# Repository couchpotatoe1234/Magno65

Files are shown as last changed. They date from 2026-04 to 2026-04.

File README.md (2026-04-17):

## Magno65
After weeks of hard work, here it is. The first prototype of the Magno65.
Screenshot 2026-04-17 at 3 54 28 PM
It will use N52 Neodymium magnets that are 5mmx2mm in the PCB and on the bottom of the case, allowing the plate and the PCB to levitate. 
Screenshot 2026-04-17 at 4 45 55 PM
The case itself is two parts, so it is 3D-printable. I currently have some untested firmware that will be tested when I make this project. Heres the aproximate BOM currently.
| Name | Purpose | Quantity | Total Cost (USD) | Link | Distributor |
|---|---|---|---|---|---|
| PCB | THE PCB, THE MAIN PART | 1 | 22.60 | https://jlcpcb.com | JLCPCB |
| N52 Neodymium magnets | to levitate the PCB (smallest pack I could find) | 1 | 12.04 | https://www.greenstuffworld.com/en/neodymium-magnets-n52/503-neodymium-magnets-5x2mm-50-units-n52.html | Green Stuff World |
| Keyboard Stabilizers | to stabilize the keycaps | 1 | 7.55 | https://www.temu.com/gold-plated-plate-mounted-stabilizer-for-custom-mechanical-keyboard-2u-6-25u-g-601100064817086.html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 | Temu |
| usb micro to usb-c cable | to connect the keyboard to the computer | 1 | 2.71 | https://www.temu.com/5a-type-c-to-micro-usb-fast-charging-cable-data-tansmission-stable-current-micro-usb-to-type-c-fast-charging-data-cable-for-samsung-xiaomi-huawe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 | Temu |
| Keycaps | to cap the keys | 1 | 6.93 | https://www.temu.com/chic-keycaps-with-contour-lines-featuring--cherry-profile-consisting-of-97-keys--double-shot--for---keycaps-have-see-through--and-lines-g-601100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 | Temu |
| Pi Pico | the brains of the operation | 1 | 3.11 | https://www.temu.com/1pc-sensor-module-pico-development-board--pico---supports--python-low-power-consumption--compatible-with--ide-and-csdk-industrial-electronics-no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 | Temu |
| Male pin headers | these are to connect the pi to the board | 1 | 2.27 | https://www.temu.com/dual-row-2-54mm-pitch-male-pin--40-pin-pcb-connector-strip-for--embedded-systems-g-606045468466813.html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 | Temu |
| 1N4148 | the diodes to make the keyboard work | 1 | 2.32 | https://www.temu.com/100pcs-1n4148-in4148-do-35-switch-diode-uncharged-other-material-for--g-601100062954719.html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 | Temu |
| Key switches | these are the whole point of a mechanical keyboard | 1 | 19.99 | https://www.wobkey.com/collections/all/products/keebmonkey-wobkey-rainy75-pre-lubed-hmx-jwk-switches | WOBKEY |

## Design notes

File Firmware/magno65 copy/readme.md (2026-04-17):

# magno65

magno65

*A short description of the keyboard/project*

* Keyboard Maintainer: [Couchpotatoe1234](https://github.com/Couchpotatoe1234)
* Hardware Supported: *The PCBs, controllers supported*
* Hardware Availability: *Links to where you can find this hardware*

Make example for this keyboard (after setting up your build environment):

    make magno65:default

Flashing example for this keyboard:

    make magno65:default:flash

See the [build environment setup](https://docs.qmk.fm/#/getting_started_build_tools) and the [make instructions](https://docs.qmk.fm/#/getting_started_make_guide) for more information. Brand new to QMK? Start with our [Complete Newbs Guide](https://docs.qmk.fm/#/newbs).

## Bootloader

Enter the bootloader in 3 ways:

* **Bootmagic reset**: Hold down the key at (0,0) in the matrix (usually the top left key or Escape) and plug in the keyboard
* **Physical reset button**: Briefly press the button on the back of the PCB - some may have pads you must short instead
* **Keycode in layout**: Press the key mapped to `QK_BOOT` if it is available

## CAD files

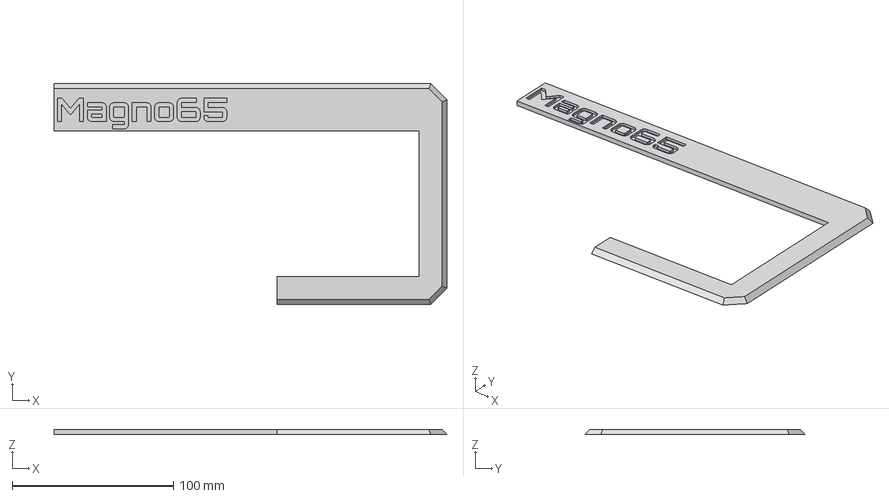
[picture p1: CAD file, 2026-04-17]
CAD/Magno65 parts - Top2.step
243.4 x 136.7 x 3.00 mm

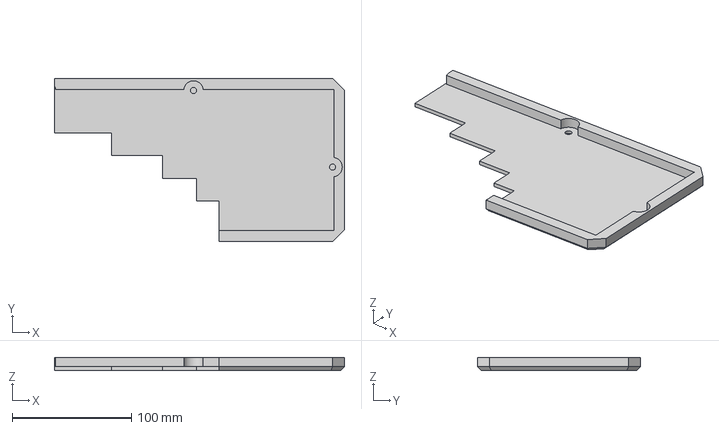
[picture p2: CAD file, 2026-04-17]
Production/Magno65 parts - Bottom1.step
243.4 x 136.7 x 10.5 mm

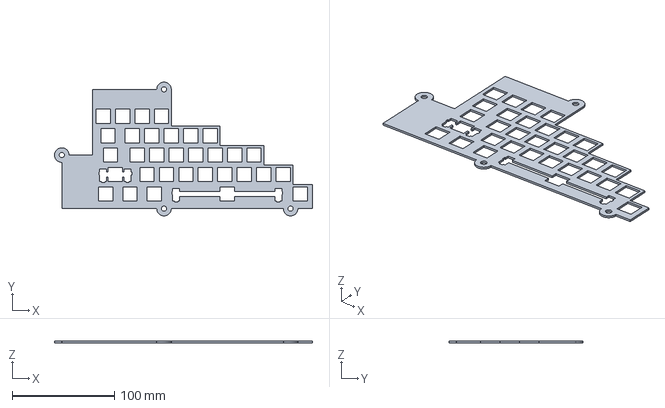
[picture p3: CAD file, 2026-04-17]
CAD/Magno65 parts - Plate1.step
252.4 x 130.9 x 1.60 mm

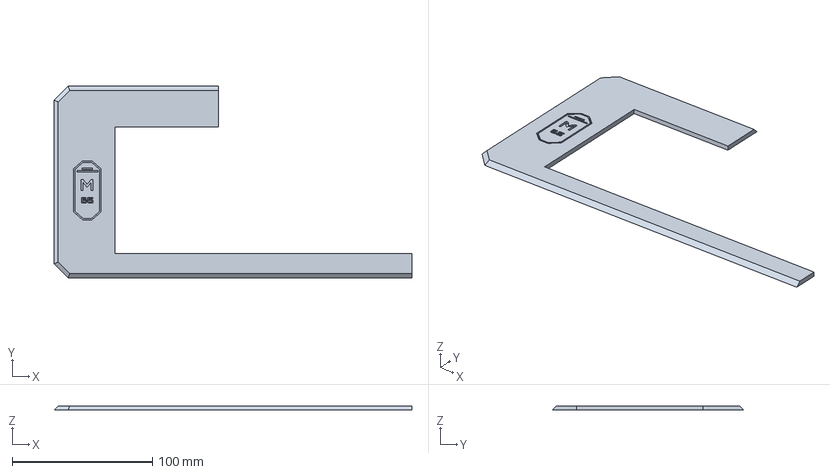
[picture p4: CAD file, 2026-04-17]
Production/Magno65 parts - Top1.step
255.3 x 136.7 x 3.00 mm

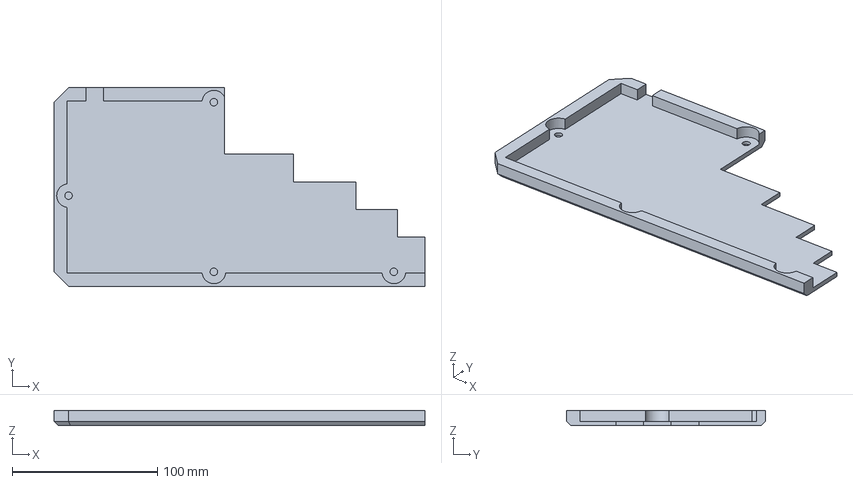
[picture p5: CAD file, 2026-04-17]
CAD/Magno65 parts - Bottom2.step
255.3 x 136.7 x 10.5 mm

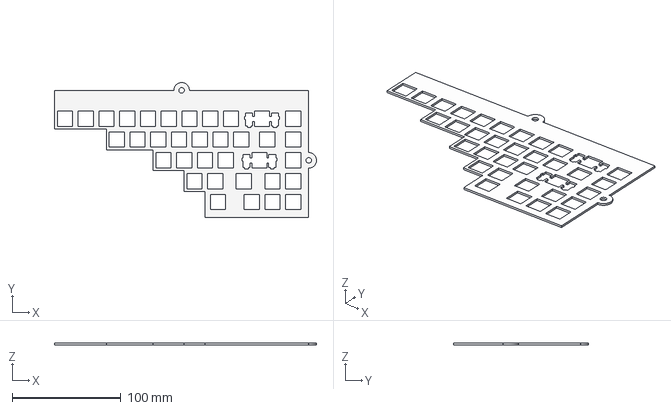
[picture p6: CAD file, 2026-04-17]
CAD/Magno65 parts - Plate2.step
240.5 x 123.8 x 1.60 mm

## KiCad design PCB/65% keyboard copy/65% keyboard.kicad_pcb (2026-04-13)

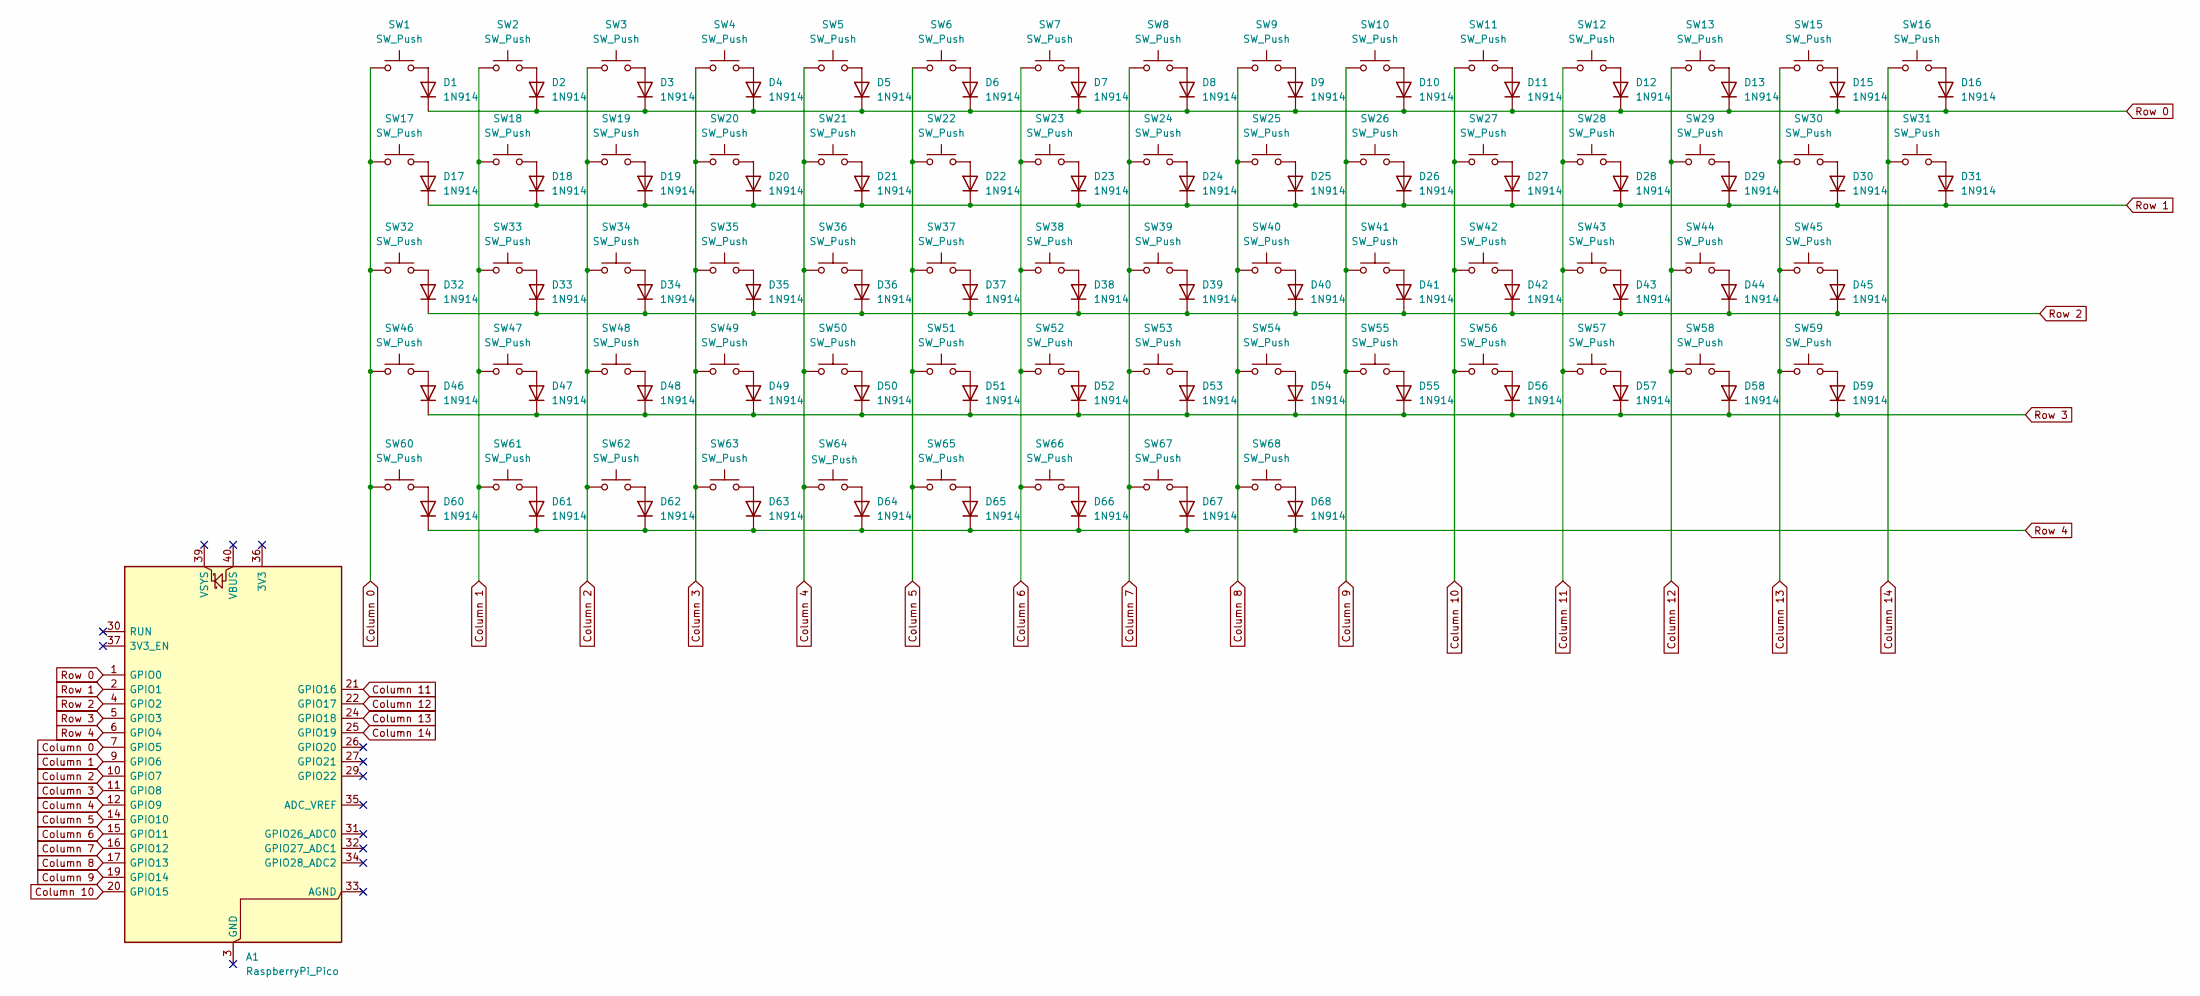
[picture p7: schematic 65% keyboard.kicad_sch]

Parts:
A1: RaspberryPi_Pico; RaspberryPi_Pico_Common_Unspecified
D1, D2, D3, D4, D5, D6, D7, D8, D9, D10, D11, D12, D13, D15, D16, D17, D18, D19, D20, D21, D22, D23, D24, D25, D26, D27, D28, D29, D30, D31, D32, D33, D34, D35, D36, D37, D38, D39, D40, D41, D42, D43, D44, D45, D46, D47, D48, D49, D50, D51, D52, D53, D54, D55, D56, D57, D58, D59, D60, D61, D62, D63, D64, D65, D66, D67, D68: 1N914; D_DO-35_SOD27_P7.62mm_Horizontal
SW1, SW2, SW3, SW4, SW5, SW6, SW7, SW8, SW9, SW10, SW11, SW12, SW13, SW16, SW17, SW18, SW19, SW20, SW21, SW22, SW23, SW24, SW25, SW26, SW27, SW28, SW29, SW30, SW31, SW32, SW33, SW34, SW35, SW36, SW37, SW38, SW39, SW40, SW41, SW42, SW43, SW45, SW47, SW48, SW49, SW50, SW51, SW52, SW53, SW54, SW55, SW56, SW57, SW58, SW59, SW60, SW61, SW64, SW65, SW66, SW67, SW68: SW_Push; SW_Cherry_MX_1.00u_PCB
SW15: SW_Push; SW_Cherry_MX_2.00u_Plate
SW44, SW46: SW_Push; SW_Cherry_MX_2.25u_Plate
SW62: SW_Push; SW_Cherry_MX_1.00u_Plate
SW63: SW_Push; SW_Cherry_MX_6.25u_Plate

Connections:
Column 0: A1.7 (GPIO5), SW1.1, SW17.1, SW32.1, SW46.1, SW60.1
Column 1: A1.9 (GPIO6), SW2.1, SW18.1, SW33.1, SW47.1, SW61.1
Column 2: A1.10 (GPIO7), SW3.1, SW19.1, SW34.1, SW48.1, SW62.1
Column 3: A1.11 (GPIO8), SW4.1, SW20.1, SW35.1, SW49.1, SW63.1
Column 4: A1.12 (GPIO9), SW5.1, SW21.1, SW36.1, SW50.1, SW64.1
Column 5: A1.14 (GPIO10), SW6.1, SW22.1, SW37.1, SW51.1, SW65.1
Column 6: A1.15 (GPIO11), SW7.1, SW23.1, SW38.1, SW52.1, SW66.1
Column 7: A1.16 (GPIO12), SW8.1, SW24.1, SW39.1, SW53.1, SW67.1
Column 8: A1.17 (GPIO13), SW9.1, SW25.1, SW40.1, SW54.1, SW68.1
Column 9: A1.19 (GPIO14), SW10.1, SW26.1, SW41.1, SW55.1
Column 10: A1.20 (GPIO15), SW11.1, SW27.1, SW42.1, SW56.1
Column 11: A1.21 (GPIO16), SW12.1, SW28.1, SW43.1, SW57.1
Column 12: A1.22 (GPIO17), SW13.1, SW29.1, SW44.1, SW58.1
Column 13: A1.24 (GPIO18), SW15.1, SW30.1, SW45.1, SW59.1
Column 14: A1.25 (GPIO19), SW16.1, SW31.1
unnamed: D1.2 (A), SW1.2
unnamed: D2.2 (A), SW2.2
unnamed: D3.2 (A), SW3.2
unnamed: D4.2 (A), SW4.2
unnamed: D5.2 (A), SW5.2
unnamed: D6.2 (A), SW6.2
unnamed: D7.2 (A), SW7.2
unnamed: D8.2 (A), SW8.2
unnamed: D9.2 (A), SW9.2
unnamed: D10.2 (A), SW10.2
unnamed: D11.2 (A), SW11.2
unnamed: D12.2 (A), SW12.2
unnamed: D13.2 (A), SW13.2
unnamed: D15.2 (A), SW15.2
unnamed: D16.2 (A), SW16.2
unnamed: D17.2 (A), SW17.2
unnamed: D18.2 (A), SW18.2
unnamed: D19.2 (A), SW19.2
unnamed: D20.2 (A), SW20.2
unnamed: D21.2 (A), SW21.2
unnamed: D22.2 (A), SW22.2
unnamed: D23.2 (A), SW23.2
unnamed: D24.2 (A), SW24.2
unnamed: D25.2 (A), SW25.2
unnamed: D26.2 (A), SW26.2
unnamed: D27.2 (A), SW27.2
unnamed: D28.2 (A), SW28.2
unnamed: D29.2 (A), SW29.2
unnamed: D30.2 (A), SW30.2
unnamed: D31.2 (A), SW31.2
unnamed: D32.2 (A), SW32.2
unnamed: D33.2 (A), SW33.2
unnamed: D34.2 (A), SW34.2
unnamed: D35.2 (A), SW35.2
unnamed: D36.2 (A), SW36.2
unnamed: D37.2 (A), SW37.2
unnamed: D38.2 (A), SW38.2
unnamed: D39.2 (A), SW39.2
unnamed: D40.2 (A), SW40.2
unnamed: D41.2 (A), SW41.2
unnamed: D42.2 (A), SW42.2
unnamed: D43.2 (A), SW43.2
unnamed: D44.2 (A), SW44.2
unnamed: D45.2 (A), SW45.2
unnamed: D46.2 (A), SW46.2
unnamed: D47.2 (A), SW47.2
unnamed: D48.2 (A), SW48.2
unnamed: D49.2 (A), SW49.2
unnamed: D50.2 (A), SW50.2
unnamed: D51.2 (A), SW51.2
unnamed: D52.2 (A), SW52.2
unnamed: D53.2 (A), SW53.2
unnamed: D54.2 (A), SW54.2
unnamed: D55.2 (A), SW55.2
unnamed: D56.2 (A), SW56.2
unnamed: D57.2 (A), SW57.2
unnamed: D58.2 (A), SW58.2
unnamed: D59.2 (A), SW59.2
unnamed: D60.2 (A), SW60.2
unnamed: D61.2 (A), SW61.2
unnamed: D62.2 (A), SW62.2
unnamed: D63.2 (A), SW63.2
unnamed: D64.2 (A), SW64.2
unnamed: D65.2 (A), SW65.2
unnamed: D66.2 (A), SW66.2
unnamed: D67.2 (A), SW67.2
unnamed: D68.2 (A), SW68.2
Row 0: A1.1 (GPIO0), D1.1 (K), D2.1 (K), D3.1 (K), D4.1 (K), D5.1 (K), D6.1 (K), D7.1 (K), D8.1 (K), D9.1 (K), D10.1 (K), D11.1 (K), D12.1 (K), D13.1 (K), D15.1 (K), D16.1 (K)
Row 1: A1.2 (GPIO1), D17.1 (K), D18.1 (K), D19.1 (K), D20.1 (K), D21.1 (K), D22.1 (K), D23.1 (K), D24.1 (K), D25.1 (K), D26.1 (K), D27.1 (K), D28.1 (K), D29.1 (K), D30.1 (K), D31.1 (K)
Row 2: A1.4 (GPIO2), D32.1 (K), D33.1 (K), D34.1 (K), D35.1 (K), D36.1 (K), D37.1 (K), D38.1 (K), D39.1 (K), D40.1 (K), D41.1 (K), D42.1 (K), D43.1 (K), D44.1 (K), D45.1 (K)
Row 3: A1.5 (GPIO3), D46.1 (K), D47.1 (K), D48.1 (K), D49.1 (K), D50.1 (K), D51.1 (K), D52.1 (K), D53.1 (K), D54.1 (K), D55.1 (K), D56.1 (K), D57.1 (K), D58.1 (K), D59.1 (K)
Row 4: A1.6 (GPIO4), D60.1 (K), D61.1 (K), D62.1 (K), D63.1 (K), D64.1 (K), D65.1 (K), D66.1 (K), D67.1 (K), D68.1 (K)

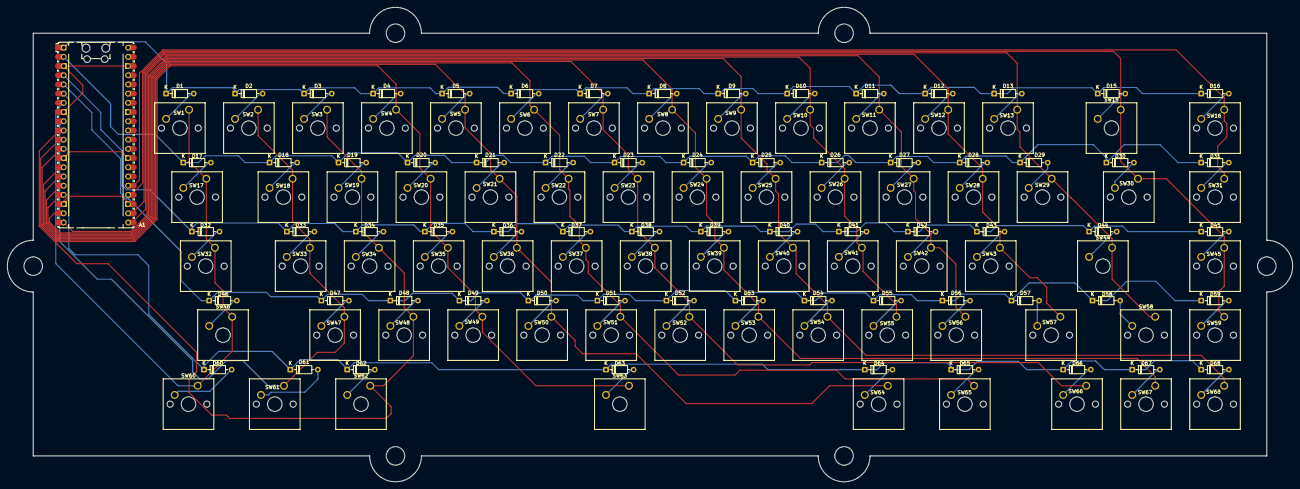
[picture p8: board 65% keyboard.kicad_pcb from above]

Board: 2 copper layers, 354.8 x 131.0 mm, 135 parts (0 on the bottom side), 87 nets.

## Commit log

2026-04-17 adding BOM
    [Magno65-bom.csv]
2026-04-17 firmware & case
    [Bottom of case.step, Plate.step, Top of case.step]
2026-04-17 Case update
    [Bottom of case.step, Magno65 parts - Bottom1.step, Magno65 parts - Bottom2.step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]
